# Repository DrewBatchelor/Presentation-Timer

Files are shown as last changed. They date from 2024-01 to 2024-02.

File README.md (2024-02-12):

# Presentation-Timer
An Arduino Neopixel LED Timer for Lightning talks and Presentations.

Fusion 360 file available (just ask.)

# Parts for the housing 
* 3D Print 5 parts in the 3MF file, PetG 50% infil
* 4 screws
* 2 M4 Thumbscrews
* 2 heat press inserts M4 from CNC kitchen
* One Acrylic Tube Dia 20mm length 500mm for 27 LEDs
* A strip of tracing paper rolled up inside the tube for diffusion. 

# Circuit parts 
* Arduino Pro-mini
* Low profile headers
* Prototype board
* 5v Regulator - optional
* Barrel jack socket
* 27 LED neopixel Strip 60LED/m
* 2 Potentiometers PCB mount
* 1 large button
* 1 small button

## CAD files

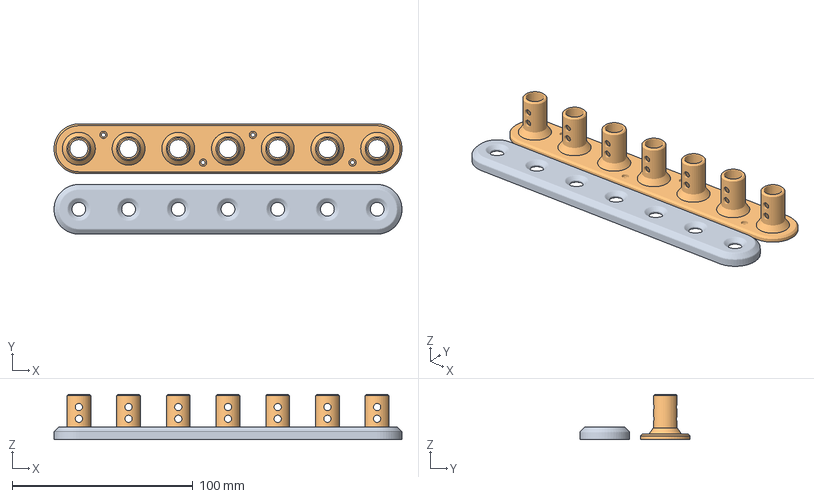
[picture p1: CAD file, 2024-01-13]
3MF Files to Print/Print Timer Box.3mf
192.5 x 61.0 x 25.0 mm

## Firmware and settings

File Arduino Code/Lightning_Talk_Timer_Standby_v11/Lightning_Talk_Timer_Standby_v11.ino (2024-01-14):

//Deek Robot Arduino Pro Mini
// ACBatchelor 14/01/24 vX
//Needs File:  Functions.ino

#include <Adafruit_NeoPixel.h>

#define LED_PIN 4
#define COLOR_ORDER GRB
#define NUM_LEDS 27

Adafruit_NeoPixel strip(NUM_LEDS, LED_PIN, NEO_GRB + NEO_KHZ800);


// Inputs
#define potPin1 A0     // select the input pin for the potentiometer
#define potPin2 A1     // select the input pin for the potentiometer
#define goButton 3     //This is the start button, it can be on any digital pin
#define resetButton 2  //This is the reset button it must be on an interrupt pin, thats 2 or 3 on a Uno but different on other boards.

// Timers

unsigned long duration1;  // total time of countdown typically 5 mins

int minMinutes = 1;
int maxMinutes = 27;

long minduration = 60000L * minMinutes;  //will be 60 000 which is 1 min in millis
//this should be at least 2*shortEnd (test at 20000)
long endTime;
long shortEnd = 10000;  //will be 10 000 which is 10 sec in millis (test at 6000)
long longEnd = 60000;   //will be 60 000 which is 1 mins in millis test at 12000)
long potStep = 60000;   // 30 000 is 0.5mins per click of the pot, so max is 6 mins

unsigned int greenInt;  //beware, max duraion about 38 min
unsigned int yellowInt;
unsigned int redInt;
unsigned int discoSpeed = 50;  //disco pace
int discoduration = 6000;

int potValue1 = 0;  // variable to store the value coming from the sensor1
int potValue2 = 0;  // variable to store the value coming from the sensor2
int bright = 100;
int brightOld =20;

// Logic
int state = 0;
void (*resetFunc)(void) = 0;  // create a standard reset function

/*--------Standby------------------------*/

int standbyDelay = 5000;
long lastChange = 0;
int TimerOld = 0;

/*--------FIRE------------------------*/
// COOLING: How much does the air cool as it rises?
// Less cooling = taller flames.  More cooling = shorter flames.
// Default 55, suggested range 20-100
#define COOLING 55  //75

// SPARKING: What chance (out of 255) is there that a new spark will be lit?
// Higher chance = more roaring fire.  Lower chance = more flickery fire.
// Default 120, suggested range 50-200.
#define SPARKING 180  //180

#define FIREDELAY 175

/*--------Colours------------------------*/
uint32_t green = strip.Color(0, bright, 0);
uint32_t yellow = strip.Color(bright / 2, bright / 2, 0);
uint32_t red = strip.Color(bright, 0, 0);
uint32_t purple = strip.Color(bright / 2, 0, bright / 2);

void setup() {
  //Serial.begin(9600);
  pinMode(resetButton, INPUT);  //have physical pullup
  pinMode(goButton, INPUT);     //have physical pullup
  pinMode(potPin1, INPUT);
  pinMode(potPin2, INPUT);

  attachInterrupt(digitalPinToInterrupt(resetButton), button_ISR, FALLING);
  attachInterrupt(digitalPinToInterrupt(goButton), buttonGo_ISR, FALLING);

  delay(100);  // sanity delay

  strip.begin();  // Initialize NeoPixel strip object (REQUIRED)
  strip.clear();
  strip.show();  // Initialize all pixels to 'off'
}

void loop() {
  switch (state) {
    case 0:  //Ready
      readyState();
      break;
    case 1:  //going
      whenGo();
      colorWipe(green, greenInt);    // Green
      colorWipe(yellow, yellowInt);  // Yellow
      colorWipe(red, redInt);        // Red
      theaterChaseRainbow(discoSpeed);
      state = 0;
      break;

      strip.clear();
      strip.show();
  }
}

/*Interrupt pin for Reset*/
void button_ISR() {
  state = 0;
  strip.clear();
  strip.show();
  resetFunc();
}

void buttonGo_ISR() {
  state = 1;
}

void whenGo() {
  strip.clear();
  strip.fill(purple, 0, 8);    
  strip.show();
  delay(400);
  strip.clear();
  TimerOld = 0; //forces it to display the time when restarted
}

void setTimes() {
  duration1 = potStep * potValue1;
  duration1 = max(duration1, minduration);  //stops it going less that 1 minute

  if (duration1 < (longEnd * 2)) {
    endTime = shortEnd;  //final should be 1 minute 60 000
  } else {
    endTime = longEnd;  //final is longer
  }
  greenInt = (duration1 - endTime) / NUM_LEDS;
  yellowInt = endTime / (2 * NUM_LEDS);
  redInt = endTime / (2 * NUM_LEDS);
}


// Change bright on a second Potentiometer
void changeBright() {
  green = strip.Color(0, bright, 0);
  yellow = strip.Color(bright / 2, bright / 2, 0);
  red = strip.Color(bright, 0, 0);
  purple = strip.Color(bright / 2, 0, bright / 2);
  brightOld = bright/5;
}

//

/*******ready is the default state for this beast ********/
void readyState() {

  potValue1 = analogRead(potPin1);                     //0 to 1023
  potValue1 = map(potValue1, 0, 1010, 1, maxMinutes);  // should be 1024, but I got some flicker at the end so reduced to 1010 as a cludge fix
 
  potValue2 = analogRead(potPin2);                //0 to 1023
  bright = map(potValue2, 0, 1023, 40, 254);  // should be 1024, but I got some flicker at the end so reduced to 1010 as a cludge fix
 

  /*Serial.print("lastChange ");
  Serial.print(lastChange);
  Serial.print(" TimerOld ");
  Serial.print(TimerOld);
  Serial.print(" potValue1 ");
  Serial.println(potValue1);*/
  if (TimerOld != potValue1||brightOld != bright/5) {
    setTimes();
    changeBright();
    strip.fill(0, potValue1, NUM_LEDS);  
    for (int i = 0; i < potValue1; i++) {
      if ((i + 1) % 5 == 0) {
        strip.setPixelColor(i, purple);  //  Set pixel's color (in RAM)
      } else {
        strip.setPixelColor(i, green);  //  Set pixel's color (in RAM)
      }
      strip.show();
      lastChange = millis();
      TimerOld = potValue1;
    }
  delay(10);
  }

  if ((millis() - lastChange) > standbyDelay) {
    Fire(COOLING, SPARKING, FIREDELAY);
  }
}

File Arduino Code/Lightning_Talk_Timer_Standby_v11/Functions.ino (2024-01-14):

void Fire(int Cooling, int Sparking, int SpeedDelay) {
  static byte heat[NUM_LEDS];
  int cooldown;
 
  // Step 1.  Cool down every cell a little
  for( int i = 0; i < NUM_LEDS; i++) {
    cooldown = random(0, ((Cooling * 10) / NUM_LEDS) + 2);
   
    if(cooldown>heat[i]) {
      heat[i]=0;
    } else {
      heat[i]=heat[i]-cooldown;
    }
  }
 
  // Step 2.  Heat from each cell drifts 'up' and diffuses a little
  for( int k= NUM_LEDS - 1; k >= 2; k--) {
    heat[k] = (heat[k - 1] + heat[k - 2] + heat[k - 2]) / 3;
  }
   
  // Step 3.  Randomly ignite new 'sparks' near the bottom
  if( random(255) < Sparking ) {
    int y = random(7);
    heat[y] = heat[y] + random(160,255);
    //heat[y] = random(160,255);
  }

  // Step 4.  Convert heat to LED colors
  for( int j = 0; j < NUM_LEDS; j++) {
    setPixelHeatColor(j, heat[j] );
  }

  strip.show();
  delay(SpeedDelay);
}

void setPixelHeatColor (int Pixel, byte temperature) {
  // Scale 'heat' down from 0-255 to 0-191
  byte t192 = round((temperature/255.0)*191);
 
  // calculate ramp up from
  byte heatramp = t192 & 0x3F; // 0..63
  heatramp <<= 2; // scale up to 0..252


  // figure out which third of the spectrum we're in:
  if( t192 > 0x80) {                     // hottest
    strip.setPixelColor(Pixel, heatramp, bright, bright);
  } else if( t192 > 0x40 ) {             // middle
    strip.setPixelColor(Pixel, 0, heatramp, bright);
  } else {                               // coolest
    strip.setPixelColor(Pixel, 0, 0, heatramp);
  }
}

/*------------*/




// Fill strip pixels one after another with a color. Strip is NOT cleared
// first; anything there will be covered pixel by pixel. Pass in color
// (as a single 'packed' 32-bit value, which you can get by calling
// strip.Color(red, green, blue) as shown in the loop() function above),
// and a delay time (in milliseconds) between pixels.

void colorWipe(uint32_t color, unsigned int wait) {
  for (int i = 0; i < strip.numPixels(); i++) { // For each pixel in strip...
    strip.setPixelColor(i + 1, (0, 0, 0));      //  dodgy as goes 1 over the length of the pixel strip
    strip.setPixelColor(i, color);         //  Set pixel's color (in RAM)
    strip.show();                          //  Update strip to match
    //if (state = 0){return;}
    delay(wait);                           //  Pause for a moment
   }
  }

// Theater-marquee-style chasing lights. Pass in a color (32-bit value,
// a la strip.Color(r,g,b) as mentioned above), and a delay time (in ms)
// between frames.

void theaterChase(uint32_t color, unsigned int wait) {
  for (int a = 0; a < 20; a++) {            // Repeat 10 times...
    for (int b = 0; b < 3; b++) {           //  'b' counts from 0 to 2...
      strip.clear();                        // Set all pixels in RAM to 0 (off)
      // 'c' counts up from 'b' to end of strip in steps of 3...
      for (int c = b; c < strip.numPixels(); c += 3) {
        strip.setPixelColor(c, color);     // Set pixel 'c' to value 'color'
      }
      strip.show(); // Update strip with new contents
      delay(wait);                         // Pause for a moment
    }
  }
}

// Rainbow cycle along whole strip. Pass delay time (in ms) between frames.
void rainbow(unsigned int wait) {
  // Hue of first pixel runs 3 complete loops through the color wheel.
  // Color wheel has a range of 65536 but it's OK if we roll over, so
  // just count from 0 to 3*65536. Adding 256 to firstPixelHue each time
  // means we'll make 3*65536/256 = 768 passes through this outer loop:
  for (long firstPixelHue = 0; firstPixelHue < 3 * 65536; firstPixelHue += 256) {
    for (int i = 0; i < strip.numPixels(); i++) { // For each pixel in strip...
      // Offset pixel hue by an amount to make one full revolution of the
      // color wheel (range of 65536) along the length of the strip
      // (strip.numPixels() steps):
      int pixelHue = firstPixelHue + (i * 65536L / strip.numPixels());
      // strip.ColorHSV() can take 1 or 3 arguments: a hue (0 to 65535) or
      // optionally add saturation and value (bright) (each 0 to 255).
      // Here we're using just the single-argument hue variant. The result
      // is passed through strip.gamma32() to provide 'truer' colors
      // before assigning to each pixel:
      strip.setPixelColor(i, strip.gamma32(strip.ColorHSV(pixelHue)));
    }
    strip.show(); // Update strip with new contents
    delay(wait);  // Pause for a moment
  }
}

// Rainbow-enhanced theater marquee. Pass delay time (in ms) between frames.
void theaterChaseRainbow(unsigned int wait) {
  int firstPixelHue = 0;     // First pixel starts at red (hue 0)
  for (int a = 0; a < 30; a++) { // Repeat 30 times...
    for (int b = 0; b < 3; b++) { //  'b' counts from 0 to 2...
      strip.clear();         //   Set all pixels in RAM to 0 (off)
      // 'c' counts up from 'b' to end of strip in increments of 3...
      for (int c = b; c < strip.numPixels(); c += 2) {
        // hue of pixel 'c' is offset by an amount to make one full
        // revolution of the color wheel (range 65536) along the length
        // of the strip (strip.numPixels() steps):
        int      hue   = firstPixelHue + c * 65536L / strip.numPixels();
        uint32_t color = strip.gamma32(strip.ColorHSV(hue)); // hue -> RGB
        strip.setPixelColor(c, color); // Set pixel 'c' to value 'color'
      }
      strip.show();                // Update strip with new contents
      //if (state = 0){return;}
      delay(wait);                 // Pause for a moment
      firstPixelHue += 65536 / 90; // One cycle of color wheel over 90 frames
    }
  }
}

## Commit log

2024-01-13 Starting to populate
    [Print Timer Box.3mf]
2024-01-13 Add Arduino Code
